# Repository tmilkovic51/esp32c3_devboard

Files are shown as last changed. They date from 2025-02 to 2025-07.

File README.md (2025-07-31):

# ESP32-C3 Development board
A development board integrating the socket for easily swapping the ESP32-C3-WROOM-02 module.
It also includes:
* USB type C connector connected to USB hub (Microchip USB2514Bi) with these downstream ports:
  1. USB - UART adapter (Silabs CP2102N) connected to ESP32-C3 RXD and TXD pins - can be used for serial programming
  2. ESP32-C3 USB Serial/JTAG peripheral - can be used for serial programming and/or debugging the ESP32-C3
* ESD protection diodes on USB connector (SRV05-4)
* 4x SK6805 individually addressable LEDs connected to ESP32-C3's GPIO8 pin
* Pin headers compatible with ESP32-C3-DevkitC development kit by Espressif
* Solder bridges for disconnecting the USB - UART and USB hub from ESP32-C3's pins

## PCB front:
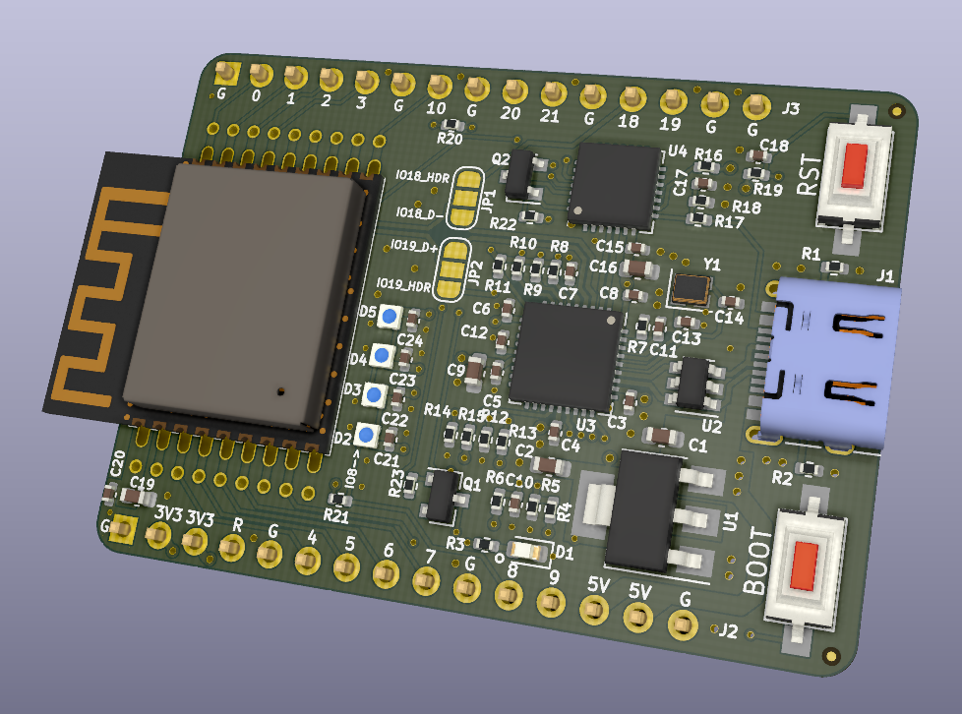
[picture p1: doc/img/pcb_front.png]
ESP32C3 devboard front


## PCB back:
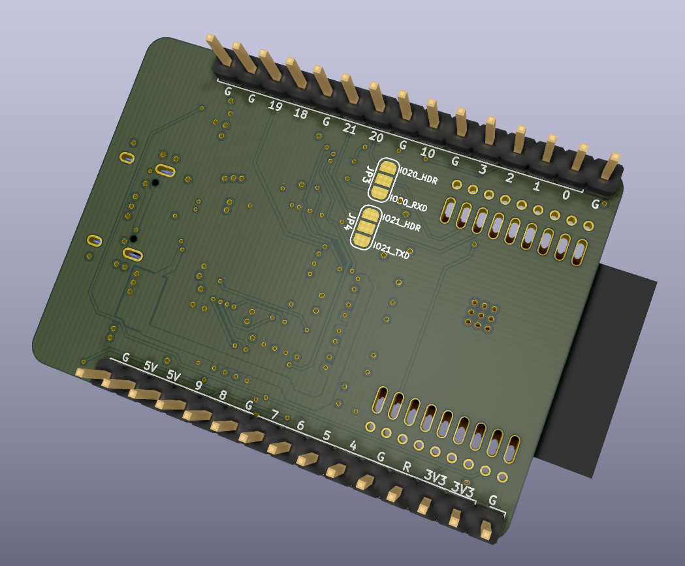
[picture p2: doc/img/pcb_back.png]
ESP32C3 devboard back


## KiCAD version
This project is compatible with KiCAD version v6.

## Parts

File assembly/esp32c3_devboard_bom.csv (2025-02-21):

Comment | Designator | Footprint | LCSC
220n | C10 | Capacitor_SMD:C_0402_1005Metric | C16772
6p8 | C13,C14 | Capacitor_SMD:C_0402_1005Metric | C1576
1uF | C17,C18 | Capacitor_SMD:C_0402_1005Metric | C52923
100n | C3,C4,C5,C6,C7,C8,C11,C12,C15,C20,C21,C22,C23,C24 | Capacitor_SMD:C_0402_1005Metric | C307331
10u | C1,C2,C9,C16,C19 | Capacitor_SMD:C_0603_1608Metric | C19702
PWR_LED | D1 | LED_SMD:LED_0603_1608Metric | C2286
SK6805 | D2,D3,D4,D5 | LED_custom:LED_SK6805_E14_1.4x1.4mm_P0.4mm | C2909055
USB_C_Receptacle_USB2.0 | J1 | Connector_USB:USB_C_Receptacle_XKB_U262-16XN-4BVC11 | C393939
S8050 | Q1,Q2 | Package_TO_SOT_SMD:SOT-23 | C2146
10K | R8,R9,R10,R11,R19,R20,R21,R22,R23 | Resistor_SMD:R_0402_1005Metric | C25744
100K | R4,R5,R6,R12,R13,R14,R15 | Resistor_SMD:R_0402_1005Metric | C25741
24K | R17 | Resistor_SMD:R_0402_1005Metric | C25769
47K | R18 | Resistor_SMD:R_0402_1005Metric | C25792
5K1 | R1,R2 | Resistor_SMD:R_0402_1005Metric | C25905
1K | R3,R16 | Resistor_SMD:R_0402_1005Metric | C11702
12K,1% | R7 | Resistor_SMD:R_0402_1005Metric | C25752
AMS1117-3.3 | U1 | Package_TO_SOT_SMD:SOT-223-3_TabPin2 | C6186
SRV05-4 | U2 | Package_TO_SOT_SMD:SOT-23-6 | C85364
USB2514B_Bi | U3 | Package_DFN_QFN:QFN-36-1EP_6x6mm_P0.5mm_EP3.7x3.7mm | C220679
CP2102N-A01-GQFN28 | U4 | Package_DFN_QFN:QFN-28-1EP_5x5mm_P0.5mm_EP3.35x3.35mm | C6568
24MHz | Y1 | Crystal:Crystal_SMD_2016-4Pin_2.0x1.6mm | C194420

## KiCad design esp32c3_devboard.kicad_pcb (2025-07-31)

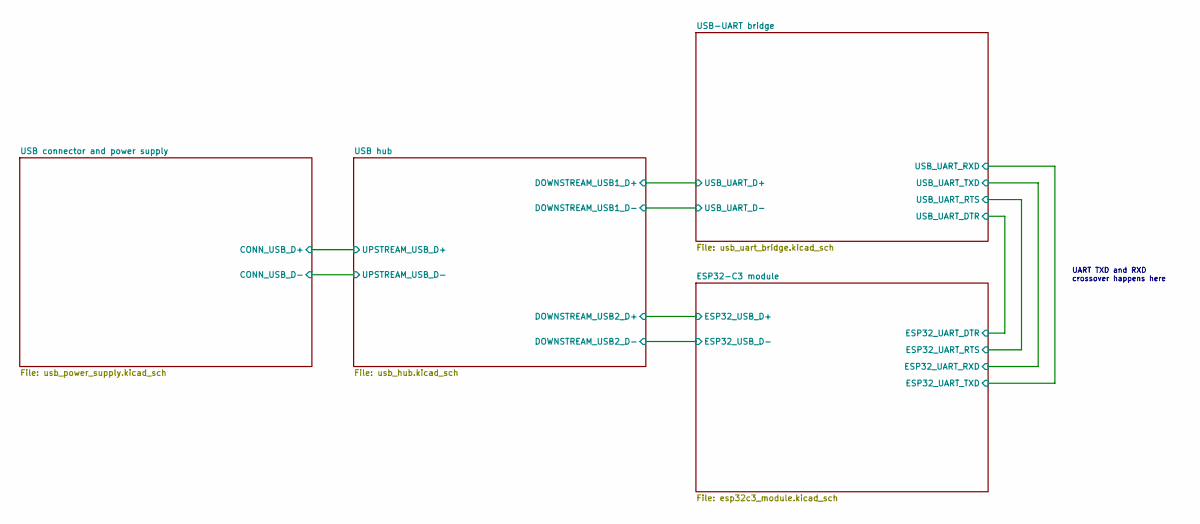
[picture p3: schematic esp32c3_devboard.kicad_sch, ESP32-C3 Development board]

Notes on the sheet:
UART TXD and RXD crossover happens here

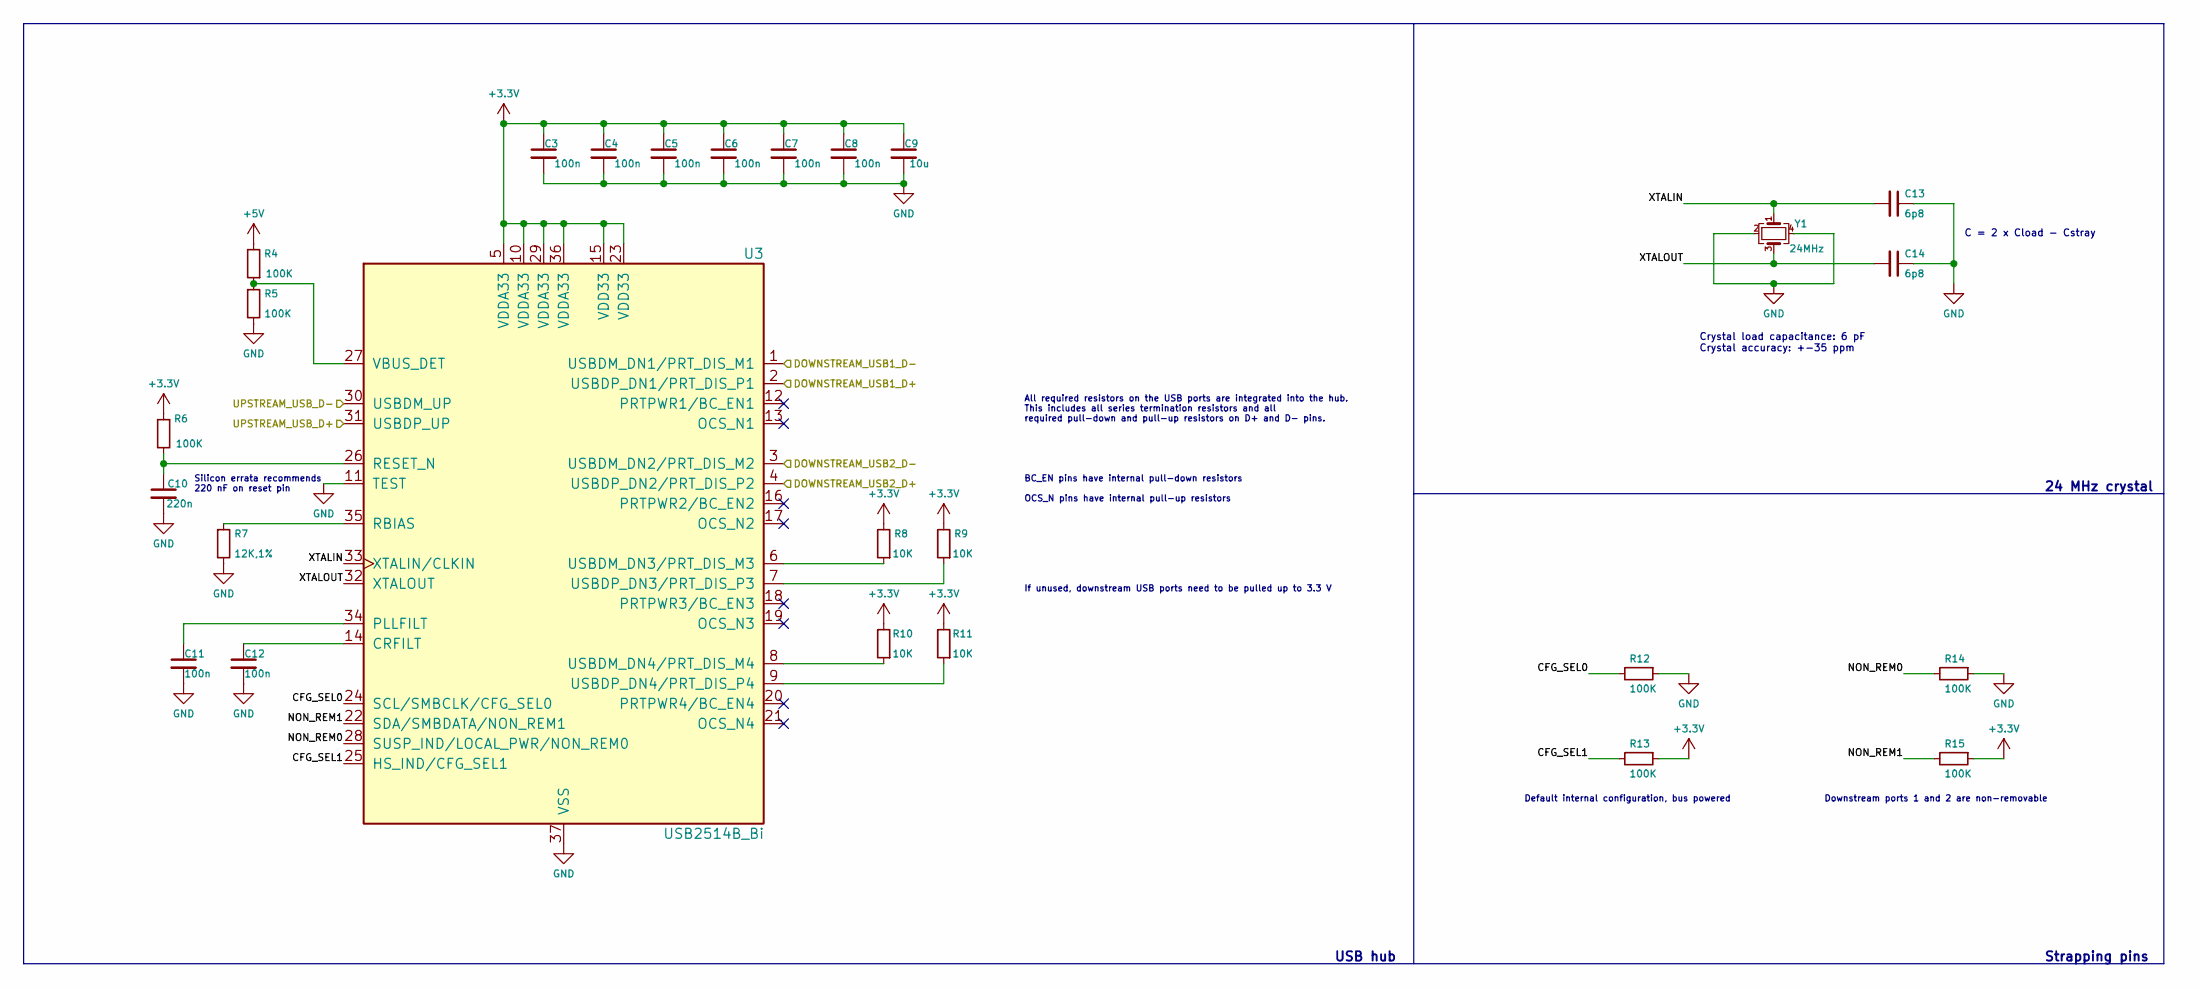
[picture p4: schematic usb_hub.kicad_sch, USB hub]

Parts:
C3, C4, C5, C6, C7, C8, C11, C12: 100n; C_0402_1005Metric; LCSC C307331
C9: 10u; C_0603_1608Metric; LCSC C19702
C10: 220n; C_0402_1005Metric; LCSC C16772
C13, C14: 6p8; C_0402_1005Metric; LCSC C1576
R4, R5, R6, R12, R13, R14, R15: 100K; R_0402_1005Metric; LCSC C25741
R7: 12K,1%; R_0402_1005Metric; LCSC C25752
R8, R9, R10, R11: 10K; R_0402_1005Metric; LCSC C25744
U3: USB2514B_Bi; QFN-36-1EP_6x6mm_P0.5mm_EP3.7x3.7mm; LCSC C220679
Y1: 24MHz; Crystal_SMD_2016-4Pin_2.0x1.6mm; LCSC C194420

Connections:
+3.3V: C3.1, C4.1, C5.1, C6.1, C7.1, C8.1, C9.1, R6.1, R8.2, R9.2, R10.2, R11.2, R13.1, R15.1, U3.5 (VDDA33), U3.10 (VDDA33), U3.15 (VDD33), U3.23 (VDD33), U3.29 (VDDA33), U3.36 (VDDA33); also elsewhere on the board
+5V: R4.2; also elsewhere on the board
/ESP32-C3 module/ESP32_USB_D+: U3.4 (USBDP_DN2/PRT_DIS_P2); also elsewhere on the board
/ESP32-C3 module/ESP32_USB_D-: U3.3 (USBDM_DN2/PRT_DIS_M2); also elsewhere on the board
/USB connector and power supply/CONN_USB_D+: U3.31 (USBDP_UP); also elsewhere on the board
/USB connector and power supply/CONN_USB_D-: U3.30 (USBDM_UP); also elsewhere on the board
/USB hub/CFG_SEL0: R12.2, U3.24 (SCL/SMBCLK/CFG_SEL0)
/USB hub/CFG_SEL1: R13.2, U3.25 (HS_IND/CFG_SEL1)
/USB hub/DOWNSTREAM_USB1_D+: U3.2 (USBDP_DN1/PRT_DIS_P1); also elsewhere on the board
/USB hub/DOWNSTREAM_USB1_D-: U3.1 (USBDM_DN1/PRT_DIS_M1); also elsewhere on the board
/USB hub/NON_REM0: R14.2, U3.28 (SUSP_IND/LOCAL_PWR/NON_REM0)
/USB hub/NON_REM1: R15.2, U3.22 (SDA/SMBDATA/NON_REM1)
/USB hub/XTALIN: C13.2, U3.33 (XTALIN/CLKIN), Y1.1
/USB hub/XTALOUT: C14.2, U3.32 (XTALOUT), Y1.3
GND: C3.2, C4.2, C5.2, C6.2, C7.2, C8.2, C9.2, C10.2, C11.2, C12.2, C13.1, C14.1, R5.2, R7.2, R12.1, R14.1, U3.11 (TEST), U3.37 (VSS), Y1.2, Y1.4; also elsewhere on the board
unnamed: C10.1, R6.2, U3.26 (RESET_N)
unnamed: C11.1, U3.34 (PLLFILT)
unnamed: C12.1, U3.14 (CRFILT)
unnamed: R4.1, R5.1, U3.27 (VBUS_DET)
unnamed: R7.1, U3.35 (RBIAS)
unnamed: R8.1, U3.6 (USBDM_DN3/PRT_DIS_M3)
unnamed: R9.1, U3.7 (USBDP_DN3/PRT_DIS_P3)
unnamed: R10.1, U3.8 (USBDM_DN4/PRT_DIS_M4)
unnamed: R11.1, U3.9 (USBDP_DN4/PRT_DIS_P4)

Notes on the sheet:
Strapping pins
C = 2 x Cload - Cstray
USB hub
24 MHz crystal
BC_EN pins have internal pull-down resistors
Downstream ports 1 and 2 are non-removable
Silicon errata recommends 220 nF on reset pin
All required resistors on the USB ports are integrated into the hub. This includes all series termination resistors and all required pull-down and pull-up resistors on D+ and D- pins.
If unused, downstream USB ports need to be pulled up to 3.3 V
Default internal configuration, bus powered
OCS_N pins have internal pull-up resistors
Crystal load capacitance: 6 pF Crystal accuracy: +-35 ppm

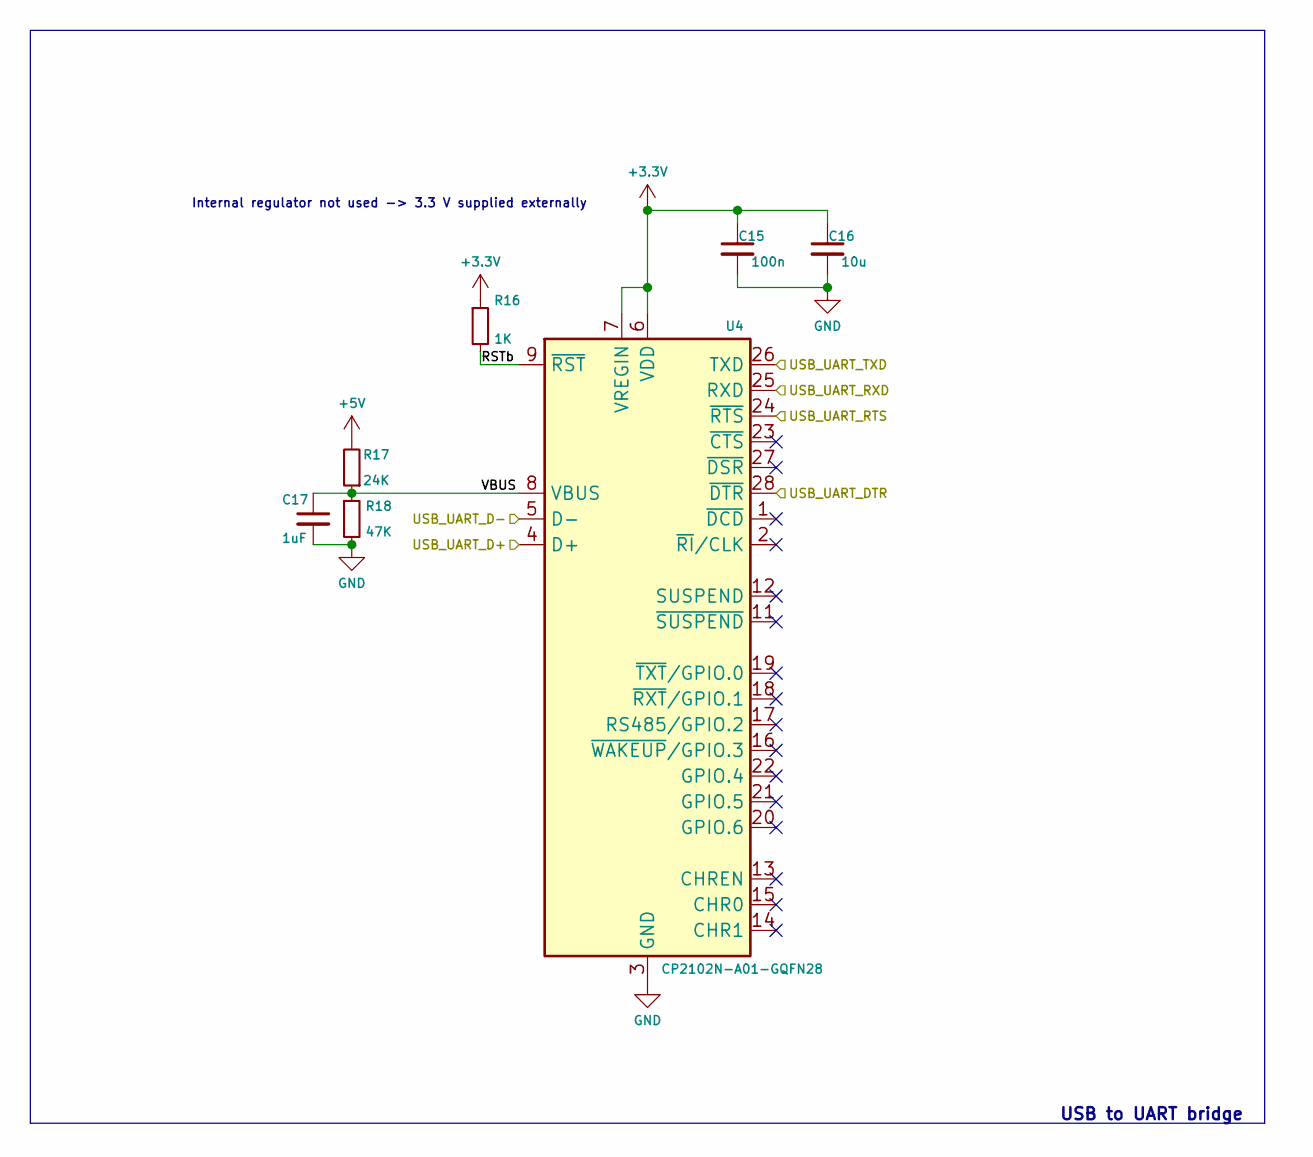
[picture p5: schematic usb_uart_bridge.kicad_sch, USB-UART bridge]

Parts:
C15: 100n; C_0402_1005Metric; LCSC C307331
C16: 10u; C_0603_1608Metric; LCSC C19702
C17: 1uF; C_0402_1005Metric; LCSC C52923
R16: 1K; R_0402_1005Metric; LCSC C11702
R17: 24K; R_0402_1005Metric; LCSC C25769
R18: 47K; R_0402_1005Metric; LCSC C25792
U4: CP2102N-A01-GQFN28; QFN-28-1EP_5x5mm_P0.5mm_EP3.35x3.35mm; LCSC C6568

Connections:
+3.3V: C15.1, C16.1, R16.1, U4.6 (VDD), U4.7 (VREGIN); also elsewhere on the board
+5V: R17.2; also elsewhere on the board
/ESP32-C3 module/ESP32_UART_DTR: U4.28 (~DTR); also elsewhere on the board
/ESP32-C3 module/ESP32_UART_RTS: U4.24 (~RTS); also elsewhere on the board
/ESP32-C3 module/ESP32_UART_RXD: U4.26 (TXD); also elsewhere on the board
/ESP32-C3 module/ESP32_UART_TXD: U4.25 (RXD); also elsewhere on the board
/USB hub/DOWNSTREAM_USB1_D+: U4.4 (D+); also elsewhere on the board
/USB hub/DOWNSTREAM_USB1_D-: U4.5 (D-); also elsewhere on the board
/USB-UART bridge/RSTb: R16.2, U4.9 (~RST)
/USB-UART bridge/VBUS: C17.1, R17.1, R18.1, U4.8 (VBUS)
GND: C15.2, C16.2, C17.2, R18.2, U4.3 (GND), U4.29 (GND); also elsewhere on the board

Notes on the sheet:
USB to UART bridge
Internal regulator not used -> 3.3 V supplied externally

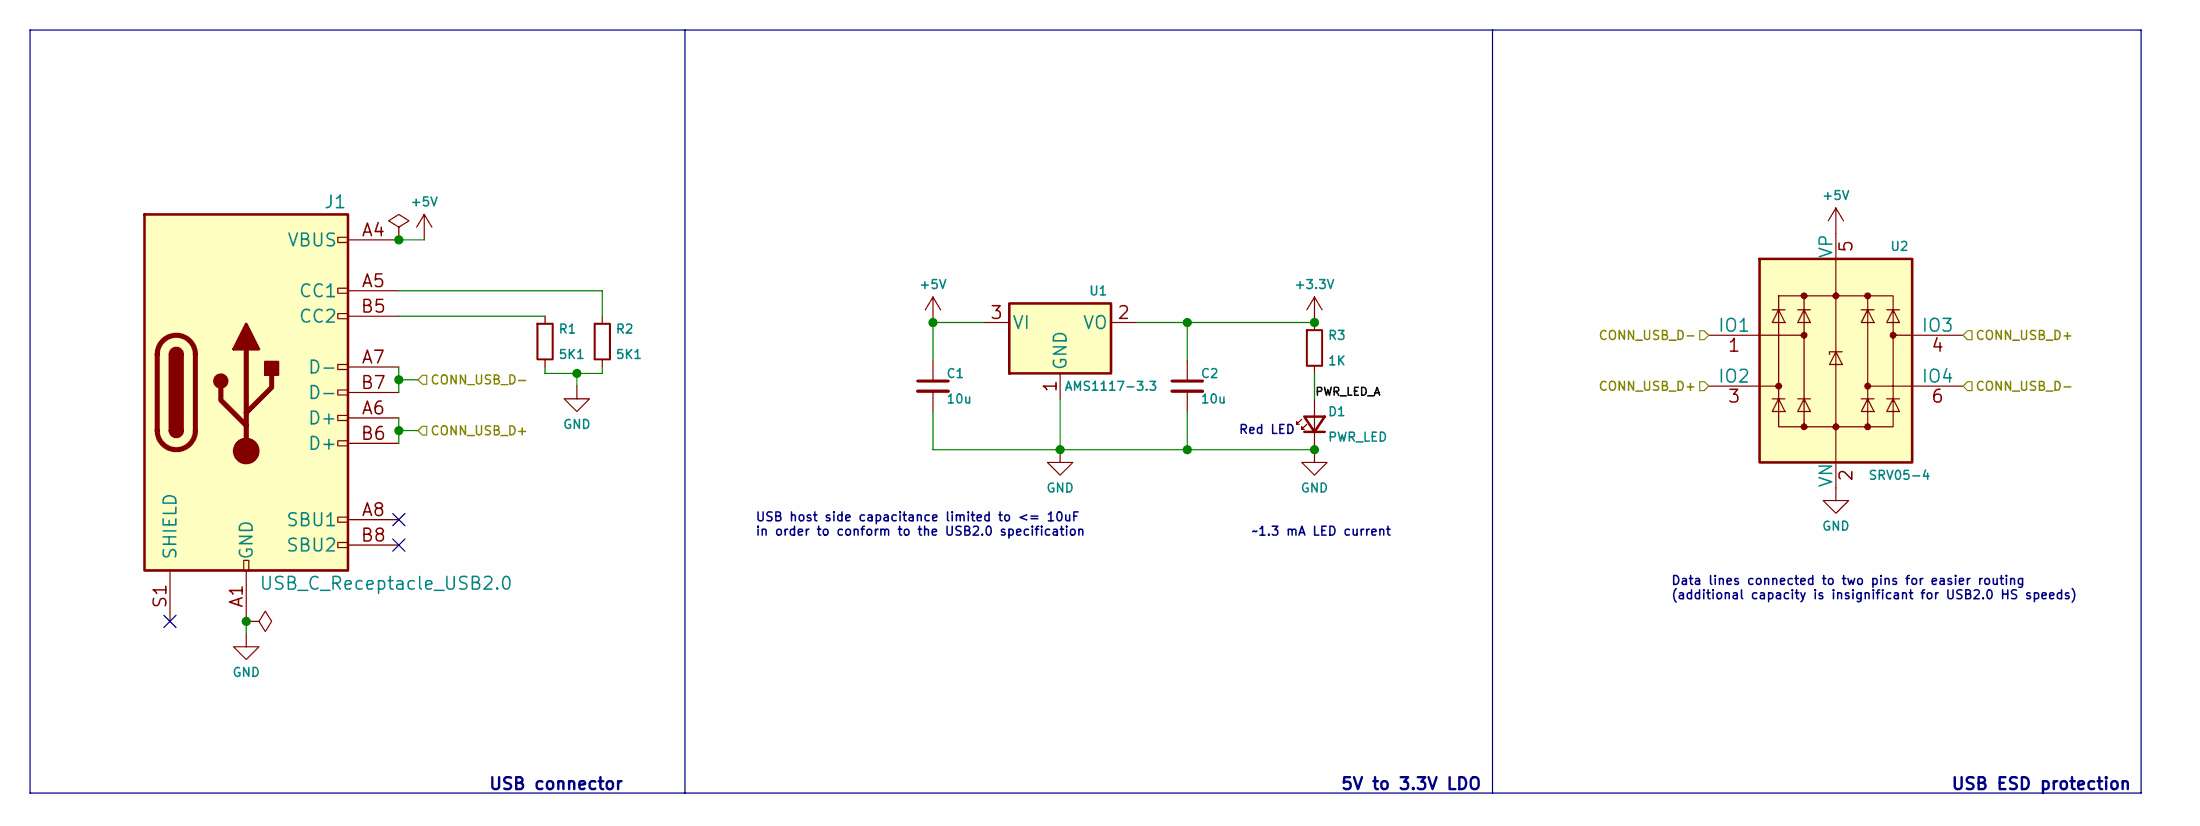
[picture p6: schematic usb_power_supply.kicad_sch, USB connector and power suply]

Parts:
C1, C2: 10u; C_0603_1608Metric; LCSC C19702
D1: PWR_LED; LED_0603_1608Metric; LCSC C2286
J1: USB_C_Receptacle_USB2.0; USB_C_Receptacle_XKB_U262-16XN-4BVC11; LCSC C393939
R1, R2: 5K1; R_0402_1005Metric; LCSC C25905
R3: 1K; R_0402_1005Metric; LCSC C11702
U1: AMS1117-3.3; SOT-223-3_TabPin2; LCSC C6186
U2: SRV05-4; SOT-23-6; LCSC C85364

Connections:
+3.3V: C2.1, R3.1, U1.2 (VO); also elsewhere on the board
+5V: C1.1, J1.A4 (VBUS), J1.A9 (VBUS), J1.B4 (VBUS), J1.B9 (VBUS), U1.3 (VI), U2.5 (VP); also elsewhere on the board
/USB connector and power supply/CONN_USB_D+: J1.A6 (D+), J1.B6 (D+), U2.3 (IO2), U2.4 (IO3); also elsewhere on the board
/USB connector and power supply/CONN_USB_D-: J1.A7 (D-), J1.B7 (D-), U2.1 (IO1), U2.6 (IO4); also elsewhere on the board
/USB connector and power supply/PWR_LED_A: D1.2 (A), R3.2
GND: C1.2, C2.2, D1.1 (K), J1.A1 (GND), J1.A12 (GND), J1.B1 (GND), J1.B12 (GND), R1.2, R2.2, U1.1 (GND), U2.2 (VN); also elsewhere on the board
unnamed: J1.A5 (CC1), R2.1
unnamed: J1.B5 (CC2), R1.1

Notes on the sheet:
USB ESD protection
USB connector
USB host side capacitance limited to <= 10uF in order to conform to the USB2.0 specification
5V to 3.3V LDO
~1.3 mA LED current
Red LED
Data lines connected to two pins for easier routing (additional capacity is insignificant for USB2.0 HS speeds)

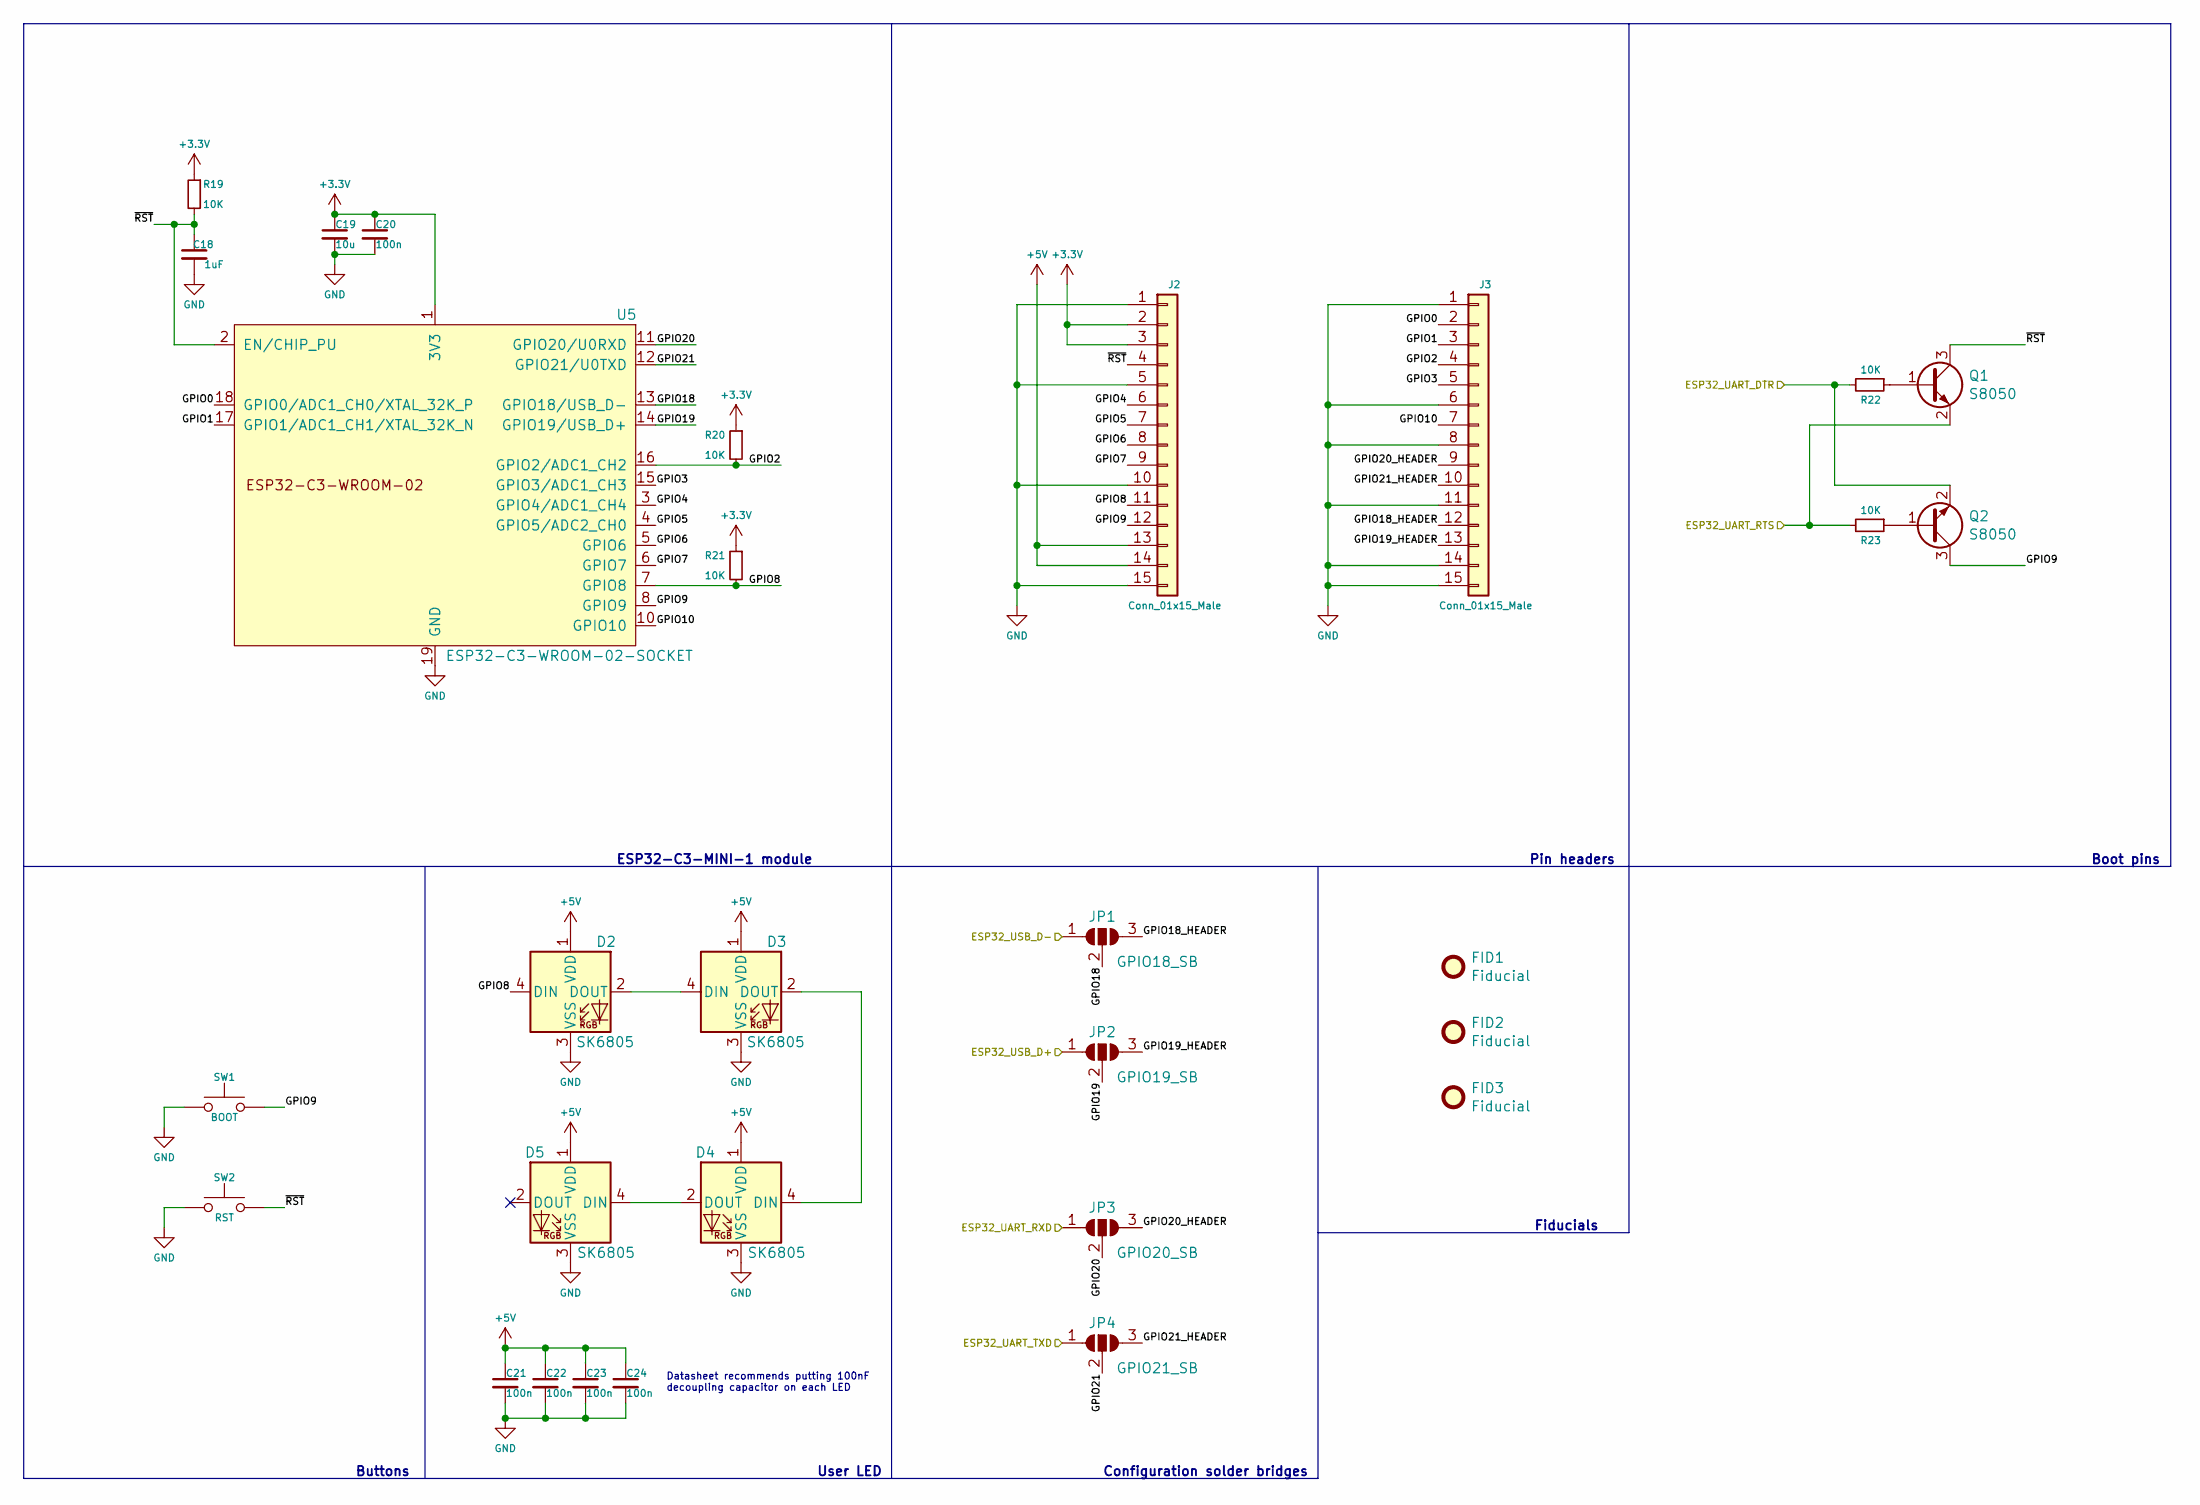
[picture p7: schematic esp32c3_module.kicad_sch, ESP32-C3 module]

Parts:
C18: 1uF; C_0402_1005Metric; LCSC C52923
C19: 10u; C_0603_1608Metric; LCSC C19702
C20, C21, C22, C23, C24: 100n; C_0402_1005Metric; LCSC C307331
D2, D3, D4, D5: SK6805; LED_SK6805_E14_1.4x1.4mm_P0.4mm; LCSC C2909055
FID1, FID2, FID3: Fiducial; Fiducial_0.5mm_Mask1mm
J2, J3: Conn_01x15_Male; PinHeader_1x15_P2.54mm_Vertical
JP1: GPIO18_SB; SolderJumper-3_P1.3mm_Open_RoundedPad1.0x1.5mm
JP2: GPIO19_SB; SolderJumper-3_P1.3mm_Open_RoundedPad1.0x1.5mm
JP3: GPIO20_SB; SolderJumper-3_P1.3mm_Open_RoundedPad1.0x1.5mm
JP4: GPIO21_SB; SolderJumper-3_P1.3mm_Open_RoundedPad1.0x1.5mm
Q1, Q2: S8050; SOT-23; LCSC C2146
R19, R20, R21, R22, R23: 10K; R_0402_1005Metric; LCSC C25744
SW1: BOOT; SW_SPST_CK_RS282G05A3
SW2: RST; SW_SPST_CK_RS282G05A3
U5: ESP32-C3-WROOM-02-SOCKET

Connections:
+3.3V: C19.1, C20.1, J2.2, J2.3, R19.1, R20.1, R21.1, U5.1 (3V3); also elsewhere on the board
+5V: C21.1, C22.1, C23.1, C24.1, D2.1 (VDD), D3.1 (VDD), D4.1 (VDD), D5.1 (VDD), J2.13, J2.14; also elsewhere on the board
/ESP32-C3 module/ESP32_UART_DTR: Q2.2 (E), R22.2; also elsewhere on the board
/ESP32-C3 module/ESP32_UART_RTS: Q1.2 (E), R23.2; also elsewhere on the board
/ESP32-C3 module/ESP32_UART_RXD: JP3.1 (A); also elsewhere on the board
/ESP32-C3 module/ESP32_UART_TXD: JP4.1 (A); also elsewhere on the board
/ESP32-C3 module/ESP32_USB_D+: JP2.1 (A); also elsewhere on the board
/ESP32-C3 module/ESP32_USB_D-: JP1.1 (A); also elsewhere on the board
/ESP32-C3 module/GPIO0: J3.2, U5.18 (GPIO0/ADC1_CH0/XTAL_32K_P)
/ESP32-C3 module/GPIO1: J3.3, U5.17 (GPIO1/ADC1_CH1/XTAL_32K_N)
/ESP32-C3 module/GPIO2: J3.4, R20.2, U5.16 (GPIO2/ADC1_CH2)
/ESP32-C3 module/GPIO3: J3.5, U5.15 (GPIO3/ADC1_CH3)
/ESP32-C3 module/GPIO4: J2.6, U5.3 (GPIO4/ADC1_CH4)
/ESP32-C3 module/GPIO5: J2.7, U5.4 (GPIO5/ADC2_CH0)
/ESP32-C3 module/GPIO6: J2.8, U5.5 (GPIO6)
/ESP32-C3 module/GPIO7: J2.9, U5.6 (GPIO7)
/ESP32-C3 module/GPIO8: D2.4 (DIN), J2.11, R21.2, U5.7 (GPIO8)
/ESP32-C3 module/GPIO9: J2.12, Q2.3 (C), SW1.2, U5.8 (GPIO9)
/ESP32-C3 module/GPIO10: J3.7, U5.10 (GPIO10)
/ESP32-C3 module/GPIO18: JP1.2 (C), U5.13 (GPIO18/USB_D-)
/ESP32-C3 module/GPIO18_HEADER: J3.12, JP1.3 (B)
/ESP32-C3 module/GPIO19: JP2.2 (C), U5.14 (GPIO19/USB_D+)
/ESP32-C3 module/GPIO19_HEADER: J3.13, JP2.3 (B)
/ESP32-C3 module/GPIO20: JP3.2 (C), U5.11 (GPIO20/U0RXD)
/ESP32-C3 module/GPIO20_HEADER: J3.9, JP3.3 (B)
/ESP32-C3 module/GPIO21: JP4.2 (C), U5.12 (GPIO21/U0TXD)
/ESP32-C3 module/GPIO21_HEADER: J3.10, JP4.3 (B)
/ESP32-C3 module/~RST: C18.1, J2.4, Q1.3 (C), R19.2, SW2.2, U5.2 (EN/CHIP_PU)
GND: C18.2, C19.2, C20.2, C21.2, C22.2, C23.2, C24.2, D2.3 (VSS), D3.3 (VSS), D4.3 (VSS), D5.3 (VSS), J2.1, J2.5, J2.10, J2.15, J3.1, J3.6, J3.8, J3.11, J3.14, J3.15, SW1.1, SW2.1, U5.9 (GND), U5.19 (GND); also elsewhere on the board
unnamed: D2.2 (DOUT), D3.4 (DIN)
unnamed: D3.2 (DOUT), D4.4 (DIN)
unnamed: D4.2 (DOUT), D5.4 (DIN)
unnamed: Q1.1 (B), R22.1
unnamed: Q2.1 (B), R23.1

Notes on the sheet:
Configuration solder bridges
Fiducials
Boot pins
Pin headers
ESP32-C3-MINI-1 module
Datasheet recommends putting 100nF decoupling capacitor on each LED
Buttons
User LED

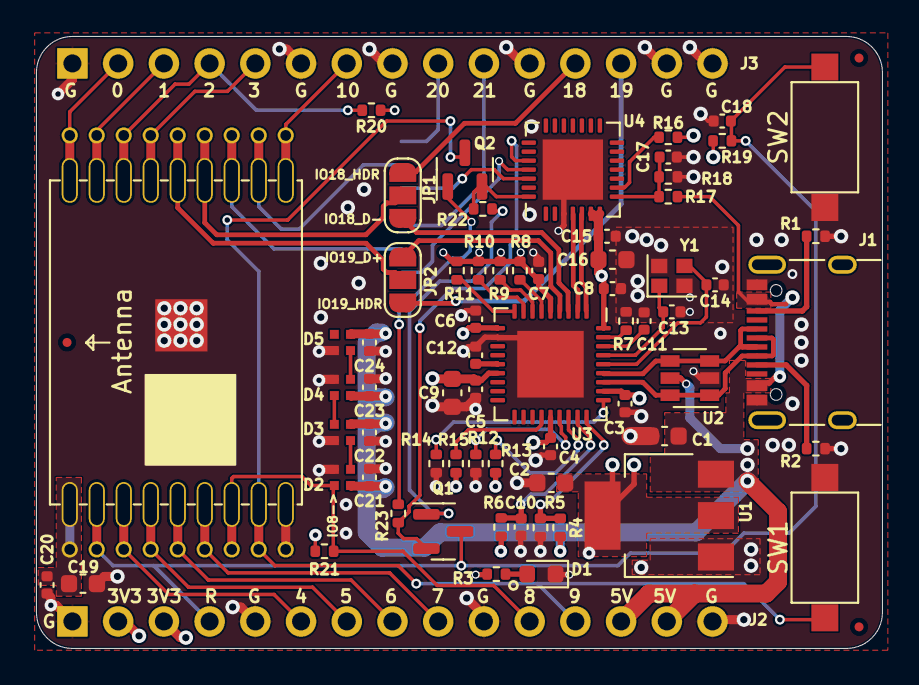
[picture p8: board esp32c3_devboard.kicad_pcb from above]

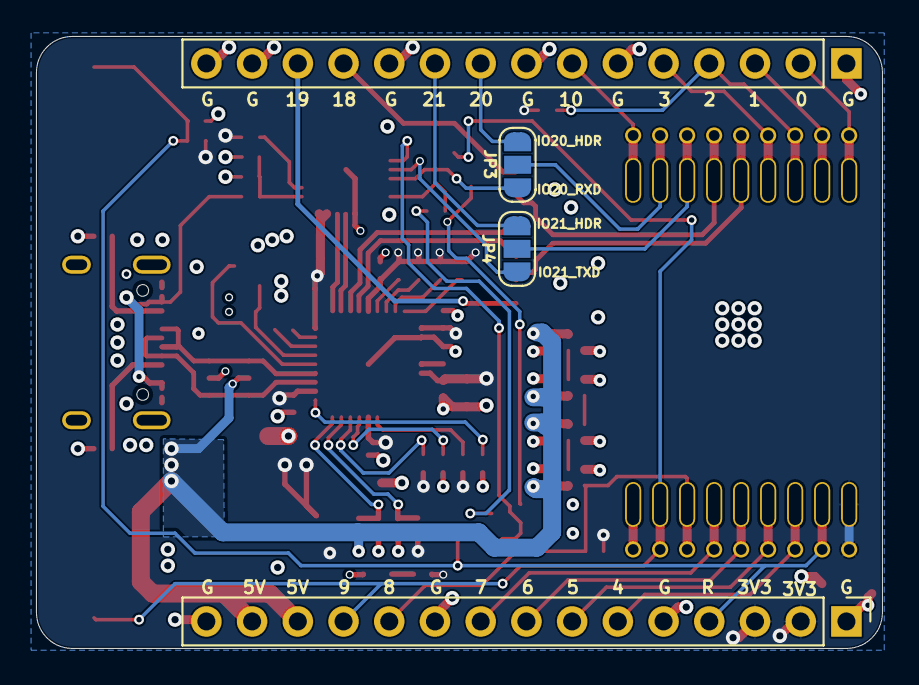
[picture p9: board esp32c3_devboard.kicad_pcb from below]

Board: 4 copper layers, 47.0 x 34.0 mm, 72 parts (4 on the bottom side), 58 nets.

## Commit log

2022-09-17 Initialize KiCad project
    Add Espressif KiCad library as submodule
    [esp32c3_devboard.kicad_pcb, esp32c3_devboard.sch]
2022-09-17 Update schematic with ESP32 module, power supply and USB to serial
    [esp32c3_devboard.sch]
2022-09-26 Place components on PCB
    [esp32c3_devboard.kicad_pcb, esp32c3_devboard.sch]
2022-09-26 Add pullup on GPIO2 strapping pin
    [esp32c3_devboard.kicad_pcb, esp32c3_devboard.sch]
2022-10-01 Add micro USB step files
    [esp32c3_devboard.kicad_pcb, esp32c3_devboard.sch]
2022-11-19 Change button silkscreen labels to RST and BOOT
    [esp32c3_devboard.kicad_pcb, esp32c3_devboard.sch]
2022-11-19 Add Microchip USB2514Bi USB hub to schematic and PCB
    [esp32c3_devboard.kicad_pcb, esp32c3_devboard.sch]
2022-11-19 Configure bootstrapping pins on USB hub IC
    [esp32c3_devboard.kicad_pcb, esp32c3_devboard.sch]
2022-11-20 Update schematic to be hierarchical
    [esp32c3_devboard.kicad_pcb, esp32c3_devboard.sch, esp32c3_module.sch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]
2023-02-01 Replace CP2102 with CH340X
    Also add BJTs to ESP32C3 strapping pins
    [esp32c3_devboard.kicad_pcb, esp32c3_module.sch, usb_power_supply.sch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]
2025-02-15 Use ESP32-C3-WROOM-02 module
    [esp32c3_devboard.kicad_pcb, esp32c3_devboard.sch, esp32c3_module.sch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]
2025-02-16 Change USB UART adapter to CP2102
    [esp32c3_devboard.kicad_pcb, esp32c3_module.sch, usb_hub.sch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]
2025-02-16 Add LCSC part numbers for all components
    [esp32c3_devboard.kicad_pcb, esp32c3_devboard.sch, esp32c3_module.sch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]
2025-02-18 Replace WS2812B with SK6805 RGB LED
    [esp32c3_devboard.kicad_pcb, esp32c3_module.sch]
2025-02-18 PCB: Rough component placement done
    [esp32c3_devboard.kicad_pcb, esp32c3_module.sch, usb_hub.sch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]
2025-02-18 PCB: Routing done
    [esp32c3_devboard.kicad_pcb]
2025-02-20 Add fiducials, finish routing
    [esp32c3_devboard.kicad_pcb, esp32c3_module.sch, usb_hub.sch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]
2025-02-21 Specify QR code location, prepare for fabrication and assembly at JLCPCB
    [esp32c3_devboard.kicad_pcb]
2025-02-21 Update README with PCB images
2025-02-21 Add files for PCB fabrication and assembly compatible with JLCPCB
    [esp32c3_devboard_bom.csv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]
2025-04-08 add 3D model for esp32 with coil pins
2025-07-31 Update project to KiCAD v6, fix BJT wrong symbol pinout
    [esp32c3_devboard.kicad_pcb, esp32c3_devboard.kicad_sch, esp32c3_devboard.sch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]

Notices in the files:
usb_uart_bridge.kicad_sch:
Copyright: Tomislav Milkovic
